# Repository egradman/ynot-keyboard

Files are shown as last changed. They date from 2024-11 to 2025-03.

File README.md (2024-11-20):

# zmq-corne6

This is the repo for my "ynot" keyboard.

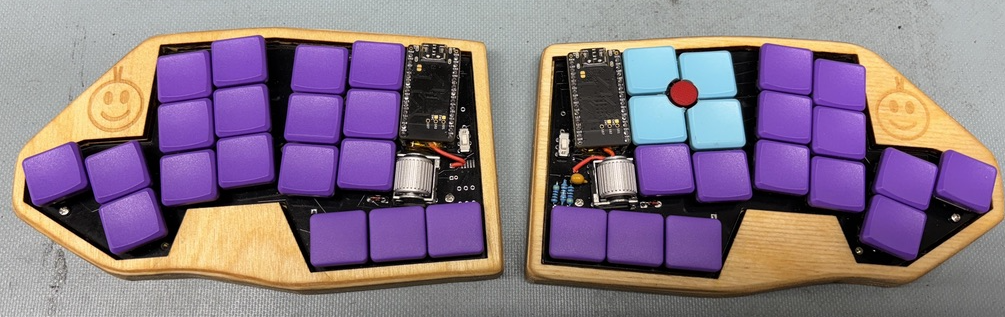
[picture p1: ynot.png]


it uses:

- Panasonic EVQWGD001 (purchased from keebd, but you can find them on aliexpress)
- nicenano
- a r61 trackpoint harvested from this keyboard https://www.ebay.com/itm/255174965511.  see https://deskthority.net/wiki/TrackPoint_Hardware for the pinout.
- choc kailh whites
- custom laser cut case
- battery:  3.7v 110mAh 301230 see (https://typeractive.xyz/products/lithium-battery-110mah)

trackpoint reset circuit as described here https://github.com/alonswartz/trackpoint

and the firmware provided by infusedkim https://github.com/infused-kim/kb_zmk_ps2_mouse_trackpoint_driver

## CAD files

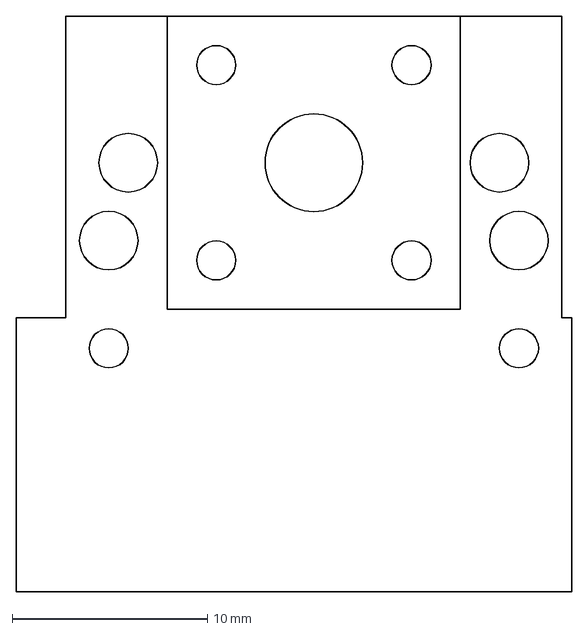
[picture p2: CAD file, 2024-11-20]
kicad_project/trackpoint.dxf
28.4 x 29.5 mm

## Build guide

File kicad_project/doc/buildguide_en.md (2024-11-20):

# Build Guide

This is the build guide for Cho-Corne-Ice, a Corne v3 variant designed for low profile and wireless
[Click here for the Corne Cherry v2 build guide](
https://github.com/foostan/crkbd/blob/master/corne-cherry/doc/v2/buildguide_en.md).

## Parts

| Name | Count | Remarks |
|:-|:-|:-|
| PCB | 1 set | |
| Top plate | 2 sheets | 1.2mm thick |
| Bottom plate | 2 sheets | |
| Display cover | 2 sheets | |
| nice!nano | 2 | |
| nice!view | 2 | |
| [Microcontroller Sockets](https://www.digikey.com/en/products/detail/mill-max-manufacturing-corp/310-43-112-41-001000/1212186) | 4 x 12pin | Mill-Max 310 series |
| [Microcontroller Pins](https://www.digikey.com/en/products/detail/mill-max-manufacturing-corp/3320-0-00-15-00-00-03-0/4147392) | 48 | Mill-Max 3320 series |
| Battery receptacle | 2 | JST-PH 2.0 SMD right angle S2B-PH-SM4-TB |
| Battery | 2 | Any 3.7v LiPo battery; 301230 fits between nice!nano and PCB |
| Reset switch | 2 | Alps SKSNLAE010 |
| Power switch | 2 | Alps SSSS811101 |
| Diodes | 42 | SMD Only (SOD-123 Package) |
| PCB sockets | 42 | Kailh Choc v1 (PG1350) |
| Key switches | 42 | Only compatible with Kailh Choc style |
| Keycaps | 42 pieces | 1u 40 pcs, 1.5u 2 pcs |
| Spacer M2 4.5mm | 10 | |
| Spacer M2 9mm | 4 | |
| Screw M2 4mm | 28 screws | |
| Rubber feet | 8 pieces | |
| USB-C cable | 2 | Avoid charge-only cables |

## Firmware preparation

It is recommended to flash nice!nano's prior to soldering.\
For more information,
please see <https://zmk.dev/docs>.

## Verification

The PCB comes with a frame for manufacturing reasons.
You can fold it by hand to remove it, but if it is difficult,
make a cut in the joint\* with a cutter or similar,
to make it easier to remove.
In addition, the joint can be cleaned with a file.

\**Joint part: There are a total of 8 parts,
which are marked in red in the image below.*

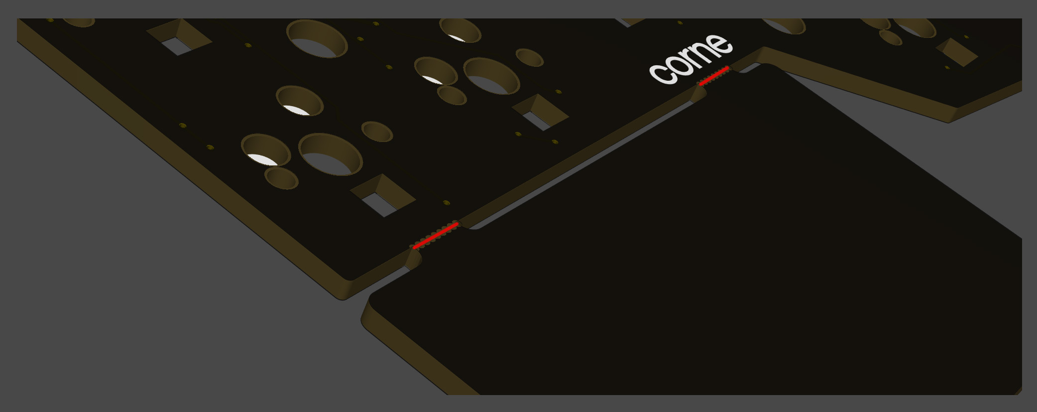
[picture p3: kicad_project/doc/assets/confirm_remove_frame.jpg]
confirm_remove_frame


## Assembly

### Diodes

Since SMD parts are very small, fine-tip/reverse-action tweezers are recommended.

**The diodes have a specific orientation**, so install with "|" marking on the diode
facing the "|" on the PCB marking: "|◁"

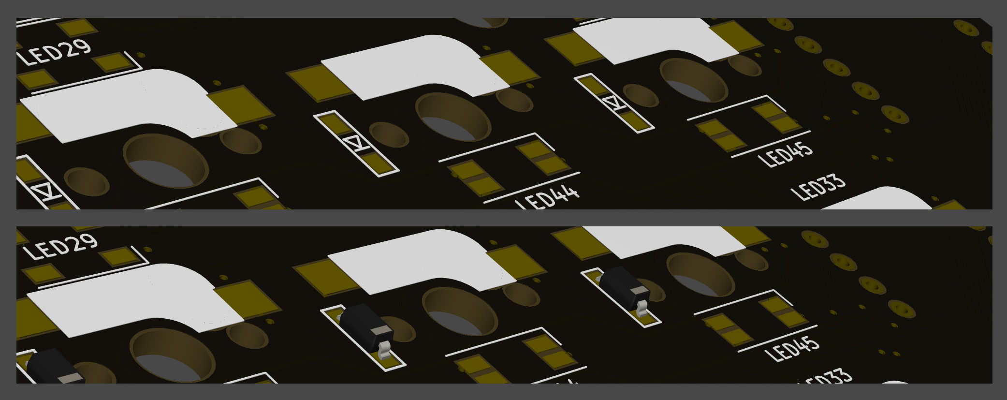
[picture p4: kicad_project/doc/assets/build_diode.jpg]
build_diode


<details>
<summary>TIPS: Tips for installing SMD parts</summary>

Begin with applying solder to only one pad.

tips_building_smd_01

Next, place SMD component while heating solder. At this time,
it is recommended to use [reverse-action tweezers](https://www.alimed.com/_resources/cache/images/product/70895A_850x480-pad.jpg),
so that you can hold the SMD part firmly without applying force,
and concentrate on alignment and soldering instead.
Also, if the soldering iron is too hot or the solder is touched too long,
the flux contained in the solder may evaporate and form a poor solder joint,
but it can be repaired later,
so at this point you should only care about attaching parts.
It's okay.

tips_building_smd_02

It is okay if the SMD component is not flush with the PCB when viewed from the side.
If it is floating, press the SMD component down with tweezers or your finger and reheat the solder.

tips_building_smd_03

Then solder the other contacts.
Be careful not to apply too much solder,
as a small amount is sufficient.
If you have applied too much,
you can remove it with a suction pump, solder wick,
or by picking it up with a soldering iron.

If the amount of solder on the preliminary solder side is small,
additional soldering is performed, and if it is a heap,
apply flux from above and heat it to clean it.

tips_building_smd_04

</details>

The diode is completed by soldering 42 pieces in total on the left and right.

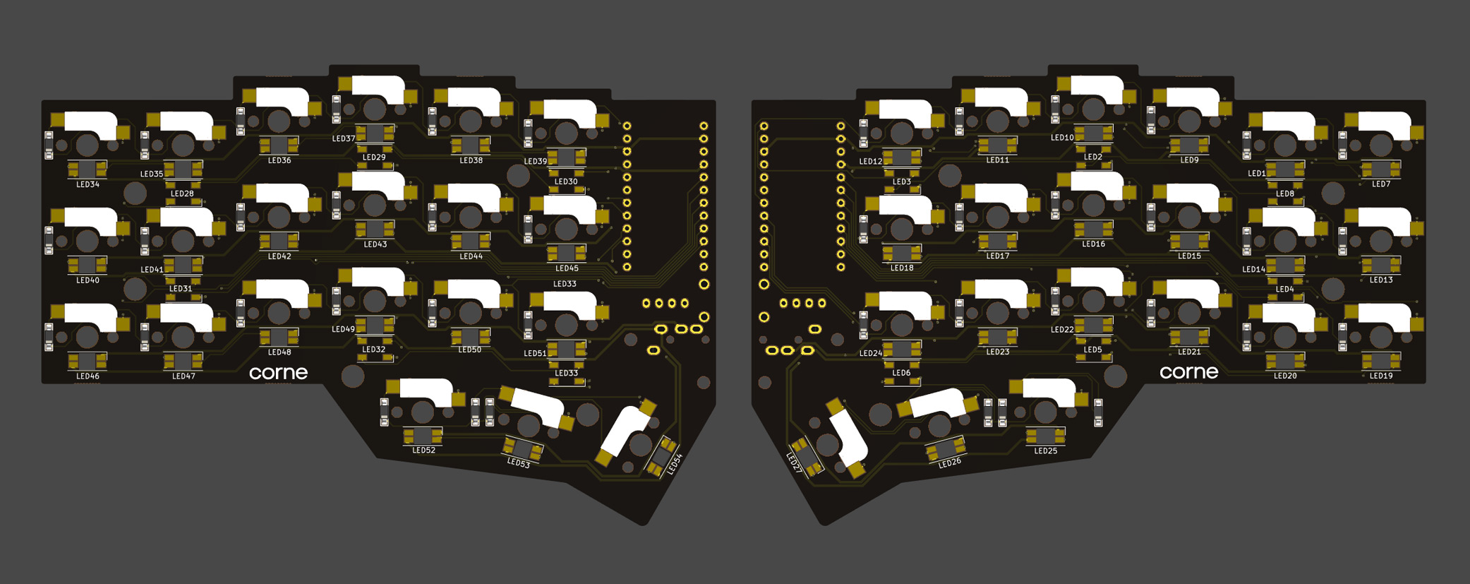
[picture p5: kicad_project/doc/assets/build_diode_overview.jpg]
build_diode_overview


### Power switch, reset switch, battery socket, pin socket for OLED

Solder the power switch, reset switch (tact switch),
and OLED pin socket.

The reset switch is a mid-mount switch and is mounted in the small cutout on the interior side of each half. the PCB will fit into the groove of the switch.

The power switch is SMD mounted to the bottom of the board directly under where the USB port will be located.

The JST-PH 2.0 2-pin battery receptacle is located near the reset switch and nice!nano header. The SMD version of this receptacle must be used, and it should be mounted facing toward the exterior of the board.

Since these parts may fall off when soldering, you can affix them with masking tape.

#### Battery

**Important**: There is no standard for battery polarity. Ensure your battery is terminated correctly before connecting to the board. Incorrect polarity will permanently damage your nice!nano.

### nice!nano

Solder headers to PCB. Then insert pins and solder nice!nano to pins. \[[Guide](https://www.digikey.com/en/products/detail/mill-max-manufacturing-corp/310-43-112-41-001000/1212186)]

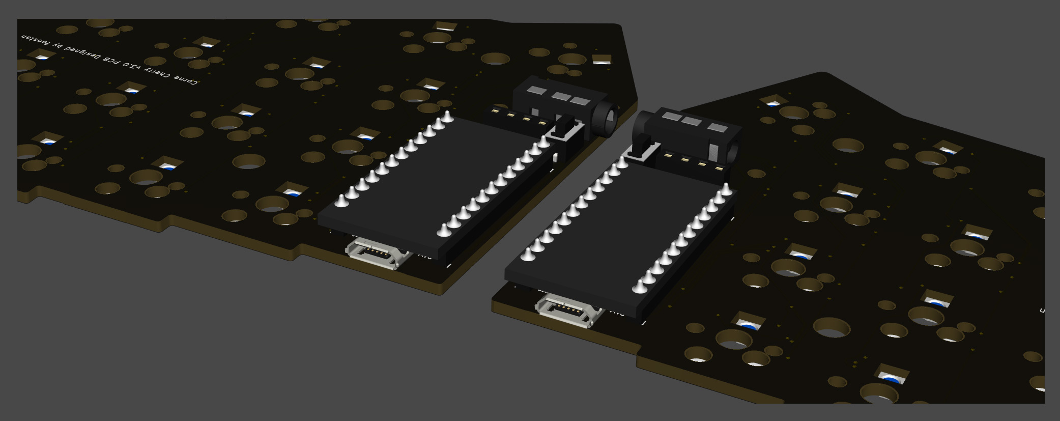
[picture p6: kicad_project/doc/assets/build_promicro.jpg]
build_promicro


If you use [spring-loaded pin headers](https://shop.yushakobo.jp/collections/all-keyboard-parts/products/31),
you do not need to solder the back side.
Please refer to the [Helix Build Guide](
https://github.com/MakotoKurauchi/helix/blob/master/Doc/buildguide_en.md#pro-micro)
for details on how to use spring-loaded pin headers.

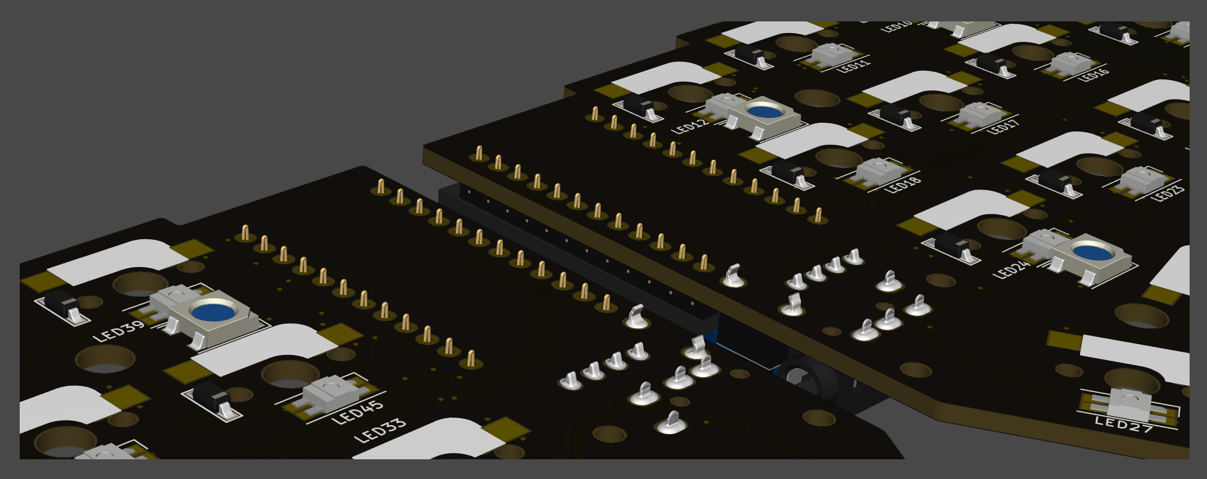
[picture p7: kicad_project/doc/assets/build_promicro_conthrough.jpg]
build_promicro_conthrough


### nice!view

Insert the pin header into the socket first, then solder the nice!view
to the pin header.
Note: Solder one pin to OLED module, then reheat solder to confirm nice!view module is level,
then solder remaining pins.

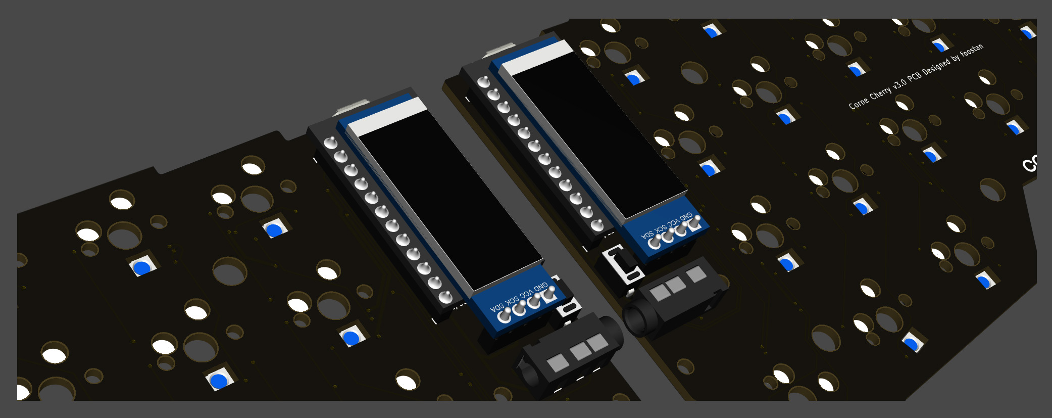
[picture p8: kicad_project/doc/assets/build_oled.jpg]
build_oled


### Operation check

Now is a good time to test your keyboard to help isolate potential problems.

To check the operation, connect left and right sides with TRRS cable,
then connect left side to the computer with USB cable.
If it is done correctly so far, shorting a hotswap socket pad with tweezers will 
output out a keypress and it will be displayed on the OLED module.

### Switch Sockets

Solder hotswap sockets according to mark on PCB as shown below.
Refer to **TIPS: Tips for installing SMD parts** section above as similar soldering
procedure is followed. 

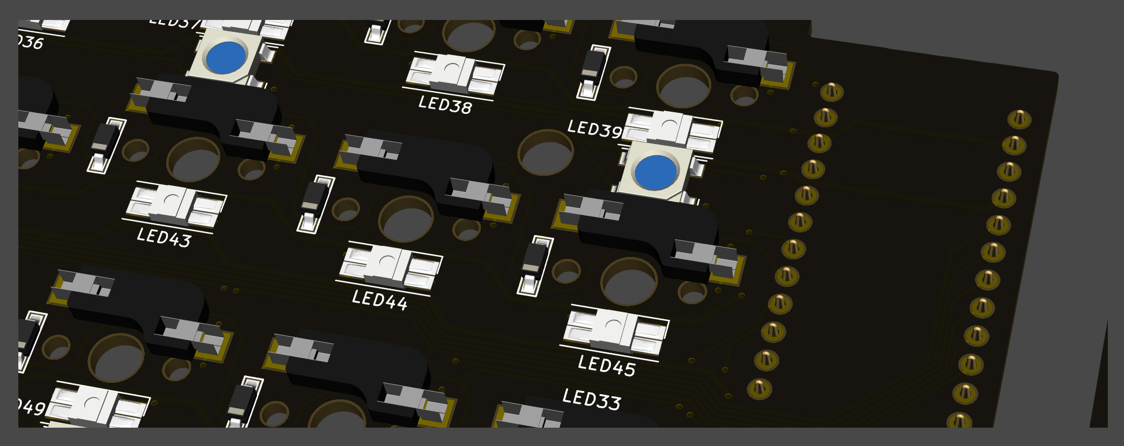
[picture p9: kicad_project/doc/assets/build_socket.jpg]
build_socket


Switch Socket soldering is completed after 42 are installed on left and right.

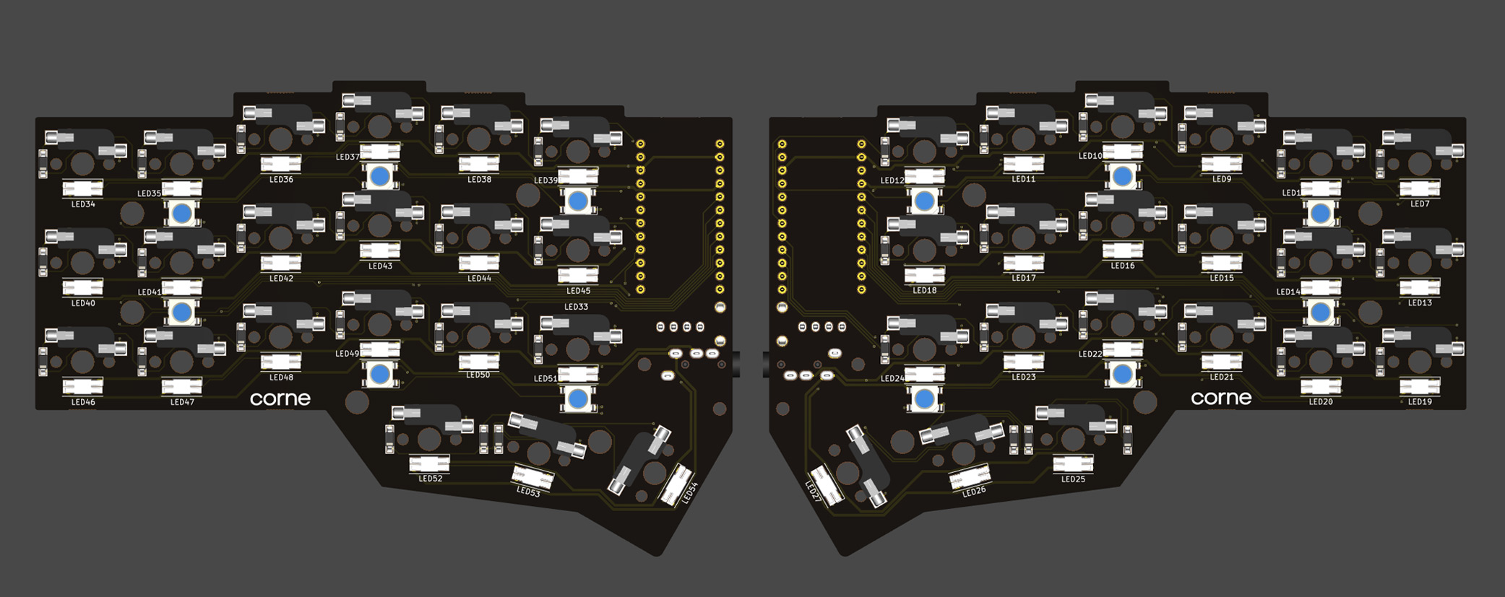
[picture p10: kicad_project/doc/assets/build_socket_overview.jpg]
build_socket_overview


### OLED protective cover

Attach the OLED protective cover with M2 9mm spacers and M2 screws.

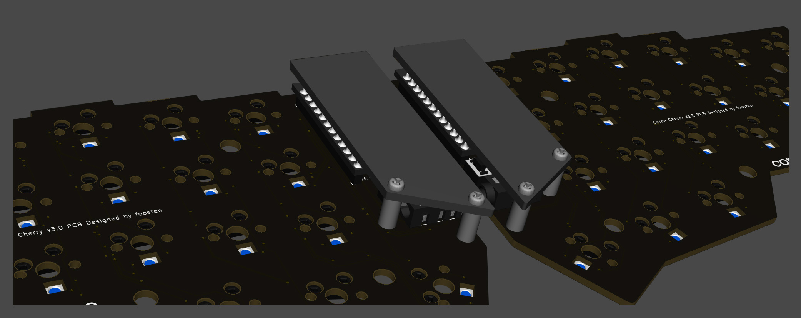
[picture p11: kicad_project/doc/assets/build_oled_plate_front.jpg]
build_oled_plate_front

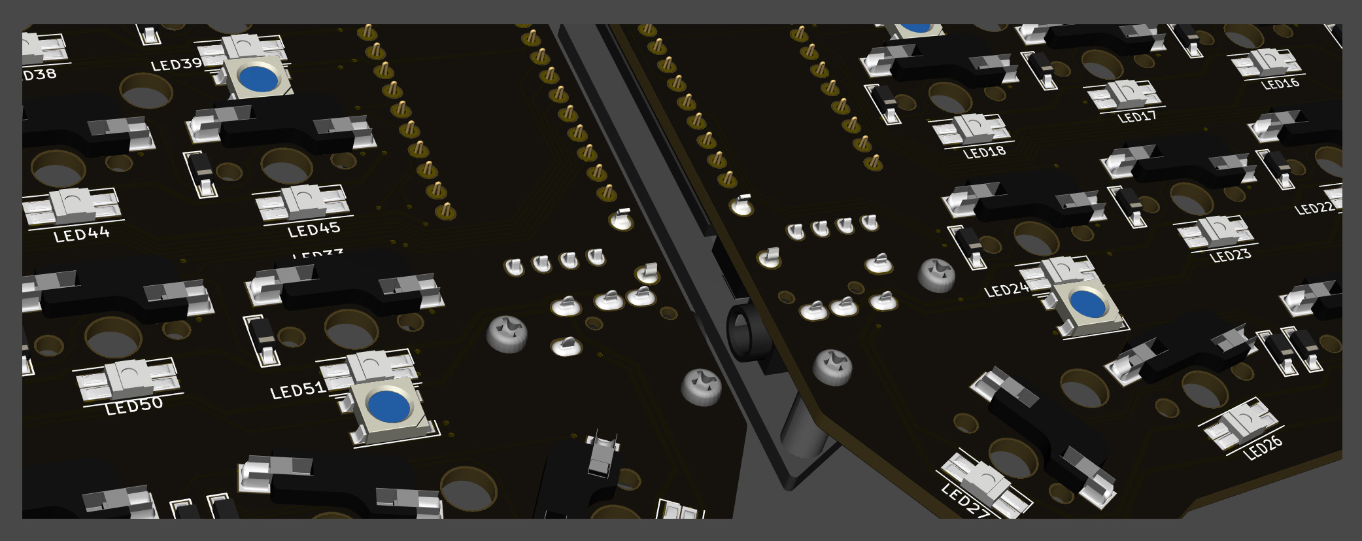
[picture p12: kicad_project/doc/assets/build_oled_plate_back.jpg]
build_oled_plate_back


### Plates & Switches

Place a few key switches into the top plate, then line up and press into PCB socket.
If you attach all the key switches to the top plate first,
it will be more difficult to fit them in the PCB sockets all at once.
So it is recommended to do a few to begin with. 

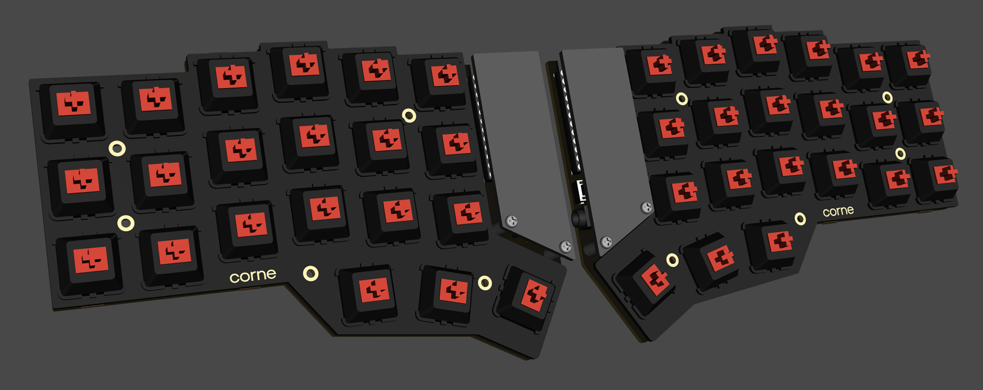
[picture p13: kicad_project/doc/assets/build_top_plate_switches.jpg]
build_top_plate_switches


Install the M2 4.5mm spacer and M2 screws on the top plate.

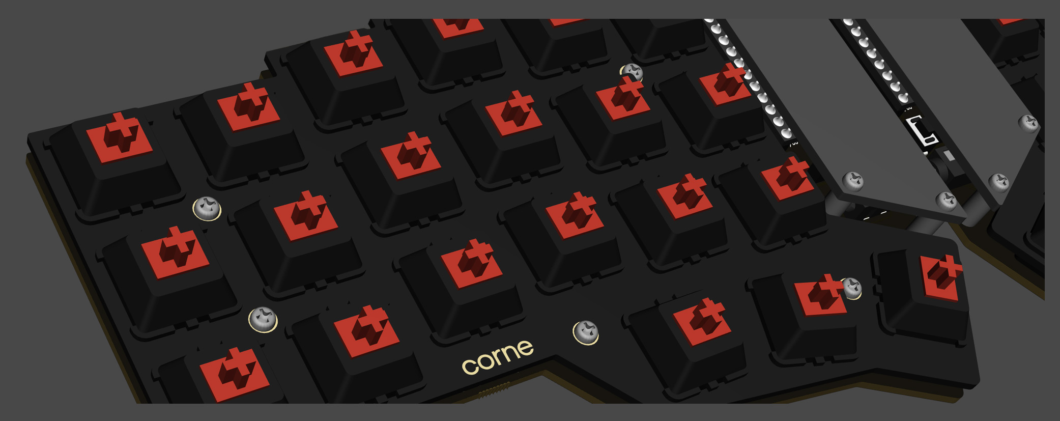
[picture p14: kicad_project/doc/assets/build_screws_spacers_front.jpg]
build_screws_spacers_front


It is easy to screw the spacer in after inserting it into the hole from the back side.

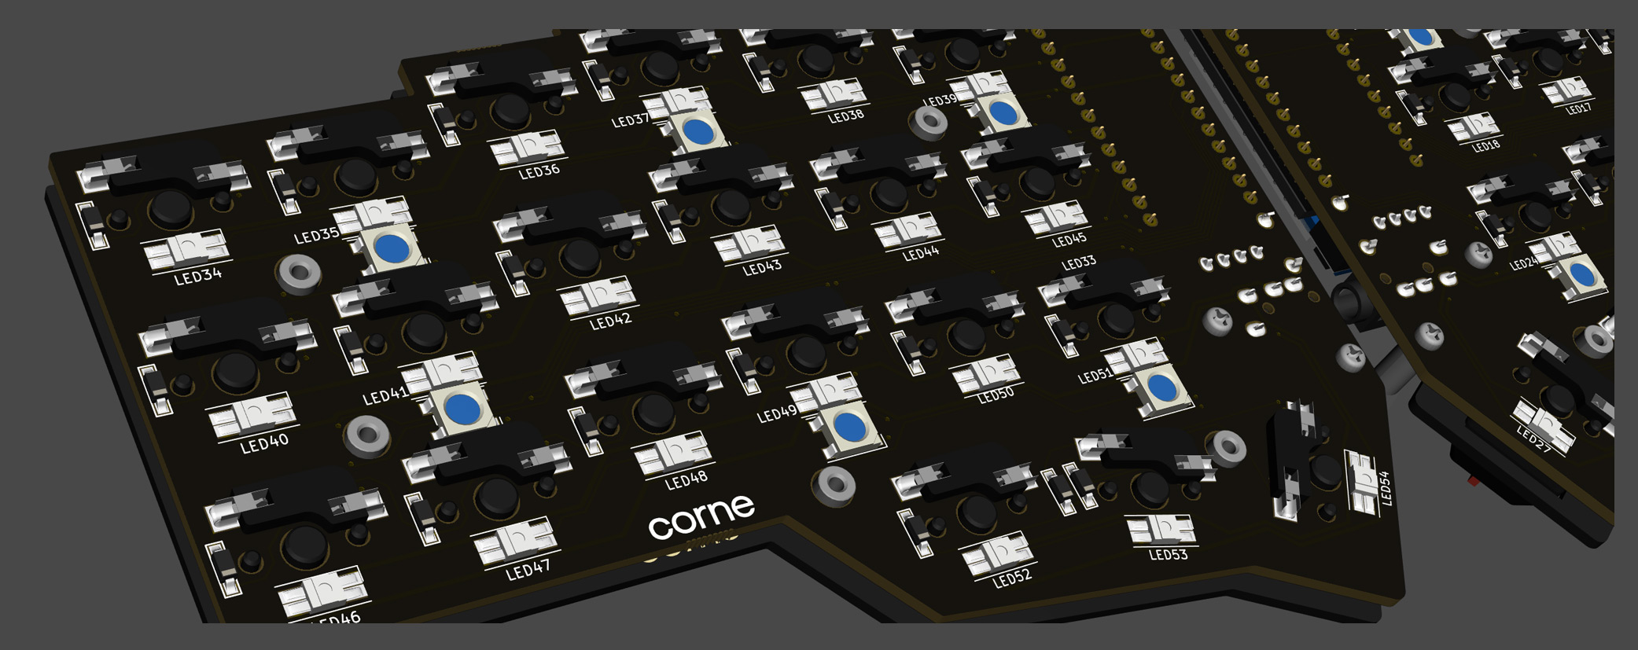
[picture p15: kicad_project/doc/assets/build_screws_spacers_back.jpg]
build_screws_spacers_back


Attach the bottom plate with M2 screws.

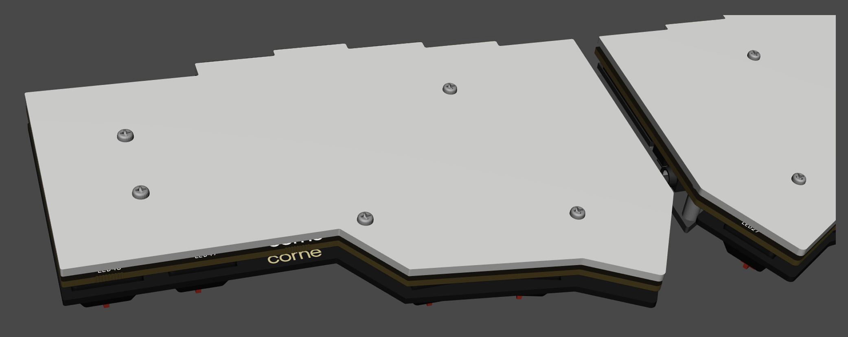
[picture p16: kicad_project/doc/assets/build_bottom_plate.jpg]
build_bottom_plate


Install the rubber feet in the following positions.

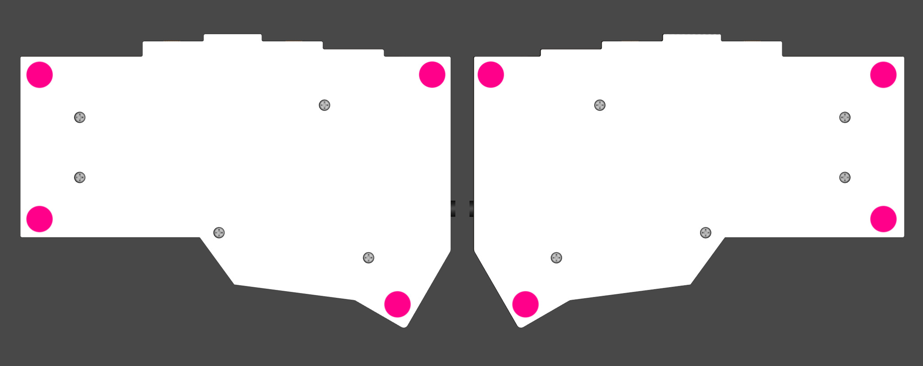
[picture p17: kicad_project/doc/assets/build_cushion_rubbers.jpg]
build_cushion_rubbers


That's it!

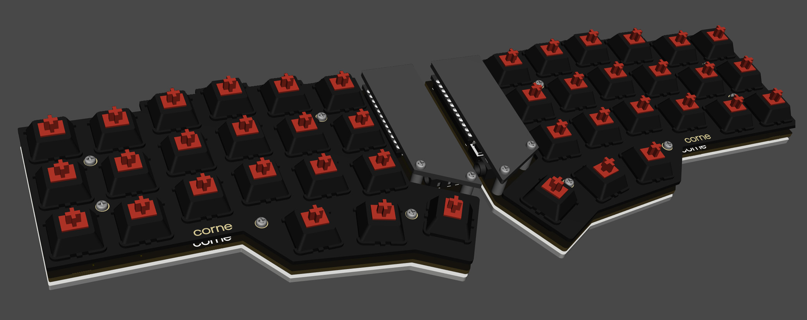
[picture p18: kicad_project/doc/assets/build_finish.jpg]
build_finish


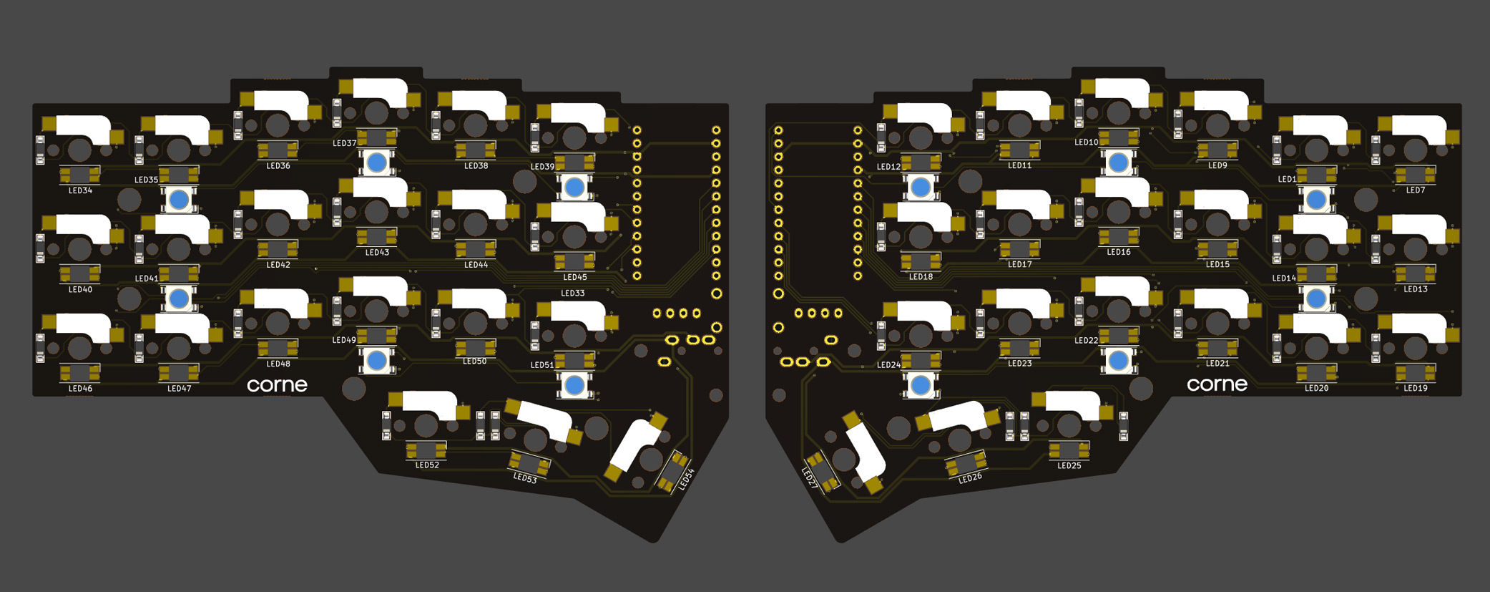
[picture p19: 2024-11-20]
kicad_project/doc/assets/build_led_undergrow_overview.jpg

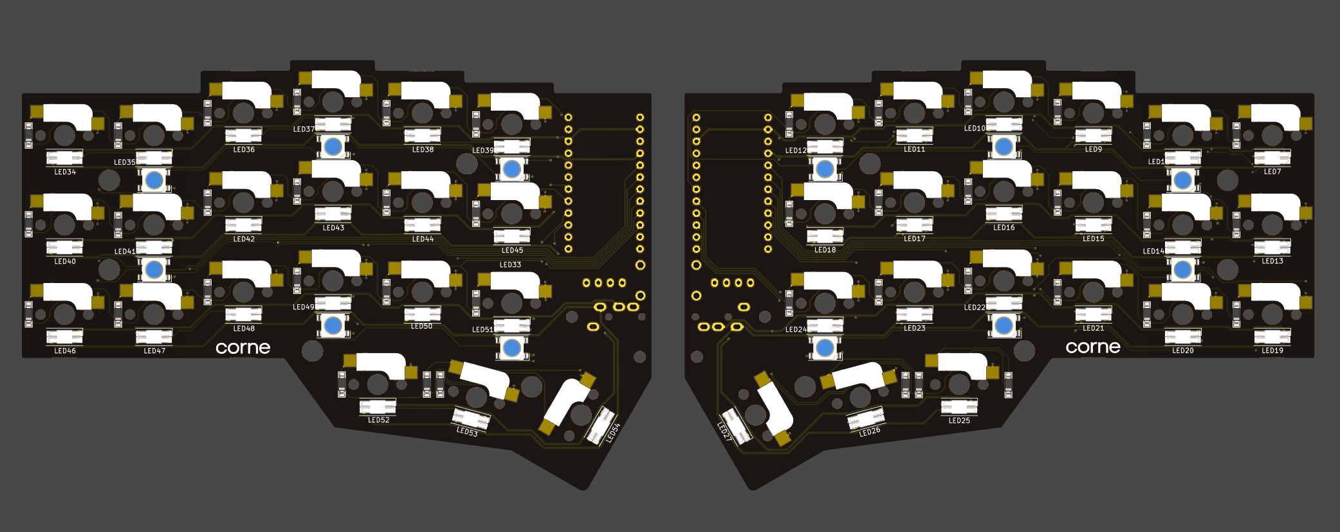
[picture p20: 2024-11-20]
kicad_project/doc/assets/build_led_back_overview.jpg

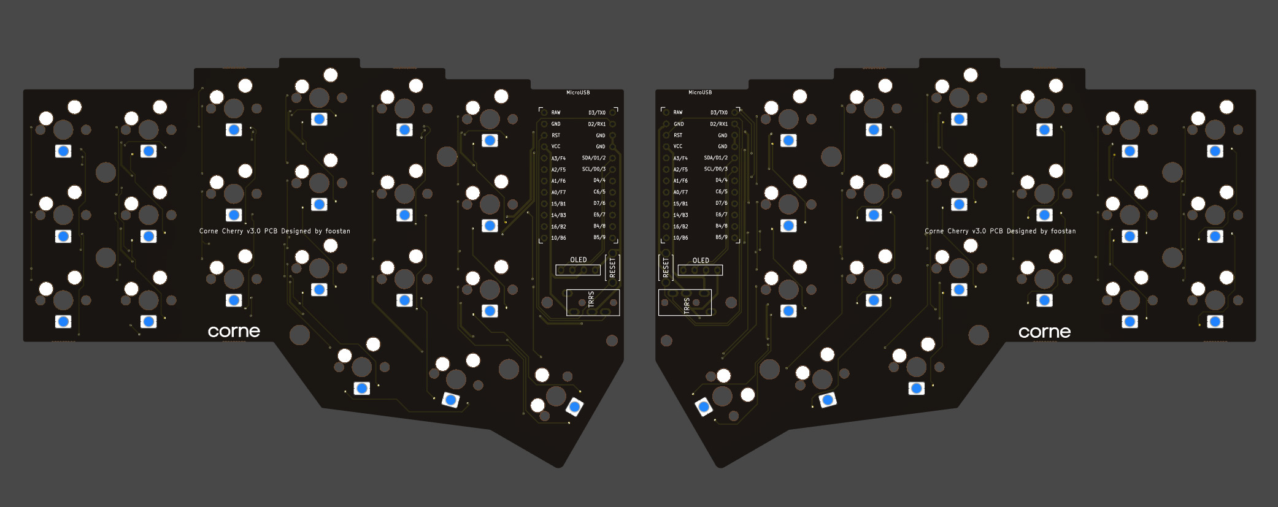
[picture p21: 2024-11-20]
kicad_project/doc/assets/build_led_front_overview.jpg

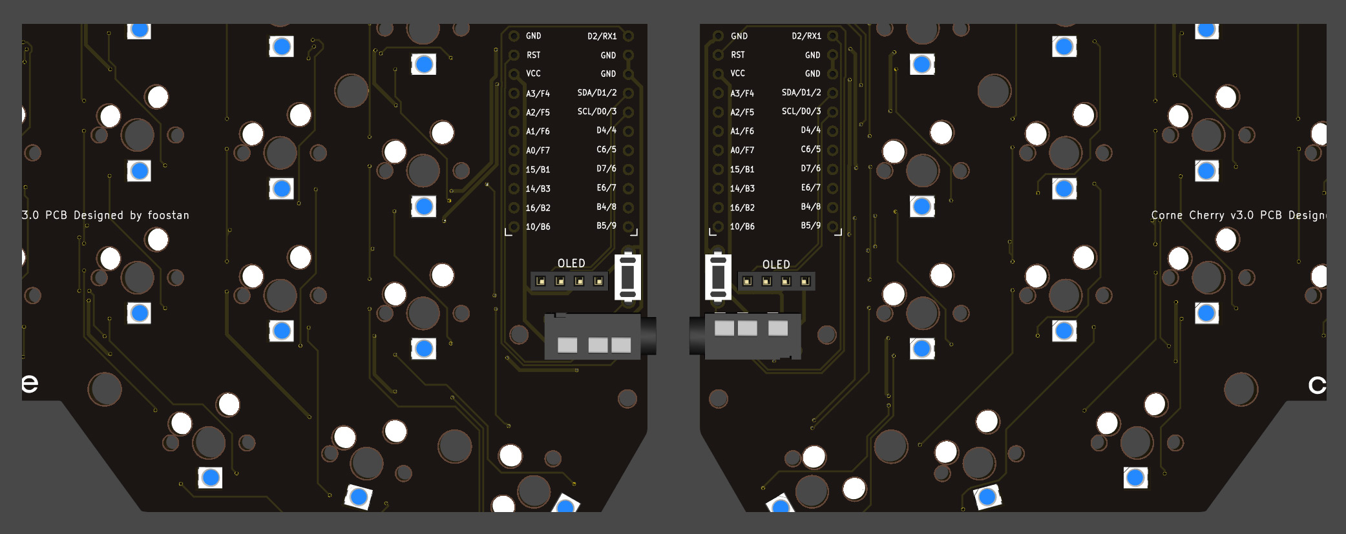
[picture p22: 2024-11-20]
kicad_project/doc/assets/build_trrs_reset_oled.jpg

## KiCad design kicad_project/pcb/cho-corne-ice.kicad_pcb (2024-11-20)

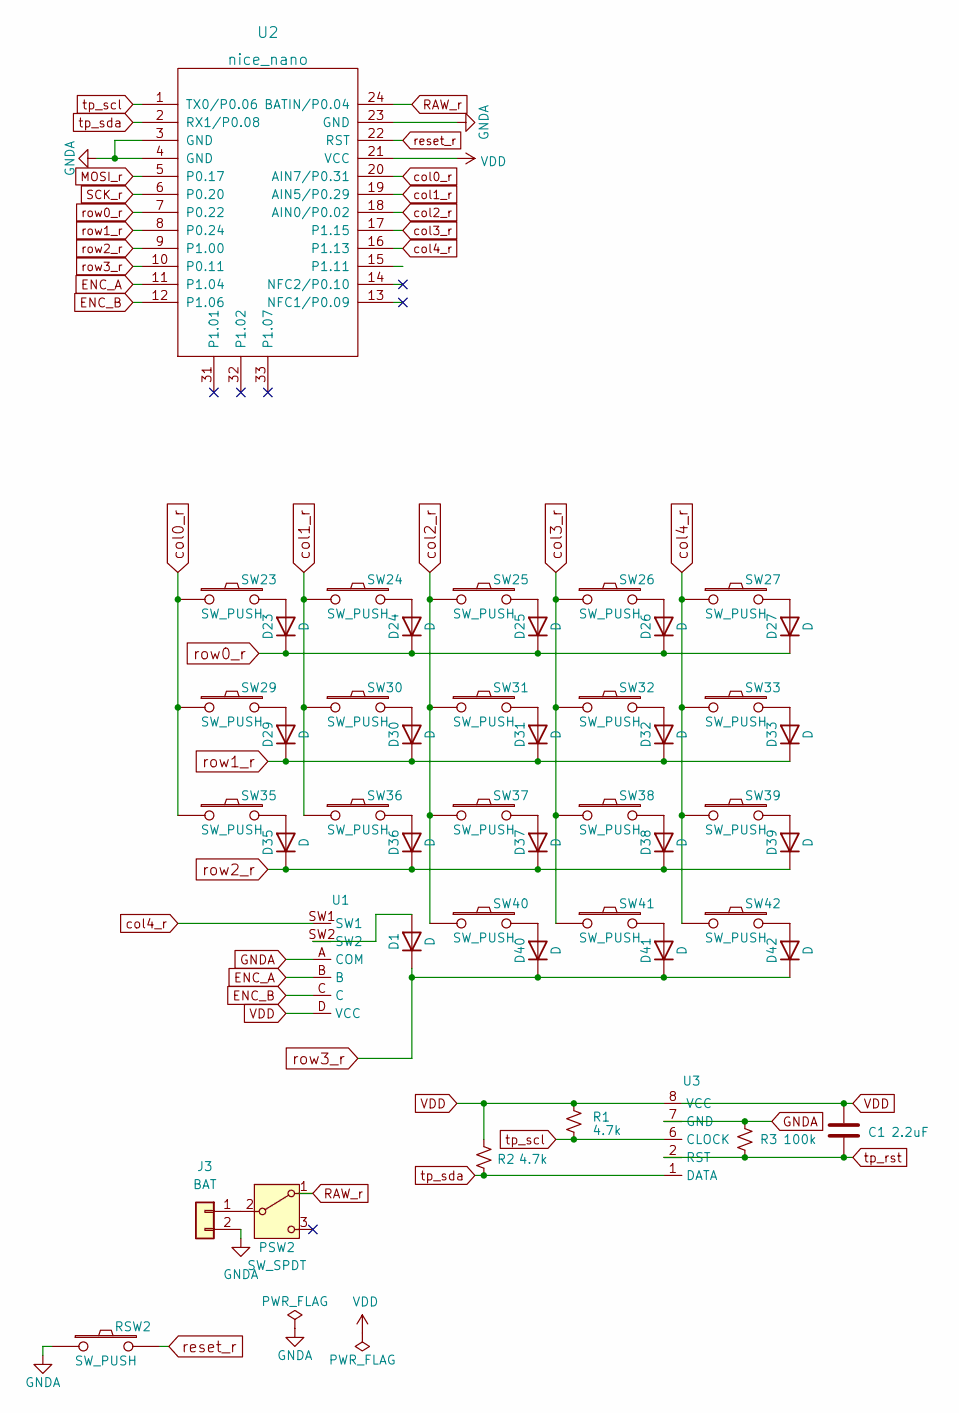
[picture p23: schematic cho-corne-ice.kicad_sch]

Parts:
C1: 2.2uF; CP_Radial_D4.0mm_P1.50mm
D1, D23, D24, D25, D26, D27, D29, D30, D31, D32, D33, D35, D36, D37, D38, D39, D40, D41, D42: D; ComboDiode
J3: BAT; SolderWire-0.1sqmm_1x02_P3.6mm_D0.4mm_OD1mm
PSW2: SW_SPDT; power_switch
R1, R2: 4.7k; R_Axial_DIN0204_L3.6mm_D1.6mm_P5.08mm_Horizontal
R3: 100k; R_Axial_DIN0204_L3.6mm_D1.6mm_P5.08mm_Horizontal
RSW2: SW_PUSH; reset_switch
SW23, SW24, SW25, SW26, SW27, SW29, SW30, SW31, SW32, SW33, SW35, SW36, SW37, SW38, SW39, SW40, SW41, SW42: SW_PUSH; SW_PG1350_reversible
U1: RollerEncoder_Panasonic_EVQWGD001
U2: nice_nano; ProMicro_jumpable_eric
U3: trackpoint

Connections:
ENC_A: U1.B, U2.11 (P1.04)
ENC_B: U1.C, U2.12 (P1.06)
GNDA: J3.2, R3.1, RSW2.1, U1.A (COM), U2.3 (GND), U2.4 (GND), U2.23 (GND), U3.7 (GND)
MOSI_r: U2.5 (P0.17)
unnamed: D1.2 (A), U1.SW2
unnamed: D23.2 (A), SW23.2
unnamed: D24.2 (A), SW24.2
unnamed: D25.2 (A), SW25.2
unnamed: D26.2 (A), SW26.2
unnamed: D27.2 (A), SW27.2
unnamed: D29.2 (A), SW29.2
unnamed: D30.2 (A), SW30.2
unnamed: D31.2 (A), SW31.2
unnamed: D32.2 (A), SW32.2
unnamed: D33.2 (A), SW33.2
unnamed: D35.2 (A), SW35.2
unnamed: D36.2 (A), SW36.2
unnamed: D37.2 (A), SW37.2
unnamed: D38.2 (A), SW38.2
unnamed: D39.2 (A), SW39.2
unnamed: D40.2 (A), SW40.2
unnamed: D41.2 (A), SW41.2
unnamed: D42.2 (A), SW42.2
unnamed: J3.1, PSW2.2 (B)
RAW_r: PSW2.1 (A), U2.24 (BATIN/P0.04)
SCK_r: U2.6 (P0.20)
VDD: C1.1, R1.1, R2.1, U1.D (VCC), U2.21 (VCC), U3.8 (VCC)
col0_r: SW23.1, SW29.1, SW35.1, U2.20 (AIN7/P0.31)
col2_r: SW25.1, SW31.1, SW37.1, SW40.1, U2.18 (AIN0/P0.02)
col3_r: SW26.1, SW32.1, SW38.1, SW41.1, U2.17 (P1.15)
reset_r: RSW2.2, U2.22 (RST)
row0_r: D23.1 (K), D24.1 (K), D25.1 (K), D26.1 (K), D27.1 (K), U2.7 (P0.22)
row1_r: D29.1 (K), D30.1 (K), D31.1 (K), D32.1 (K), D33.1 (K), U2.8 (P0.24)
row2_r: D35.1 (K), D36.1 (K), D37.1 (K), D38.1 (K), D39.1 (K), U2.9 (P1.00)
row3_r: D1.1 (K), D40.1 (K), D41.1 (K), D42.1 (K), U2.10 (P0.11)
tp_rst: C1.2, R3.2, U3.2 (RST)
tp_scl: R1.2, U2.1 (TX0/P0.06), U3.6 (CLOCK)
tp_sda: R2.2, U2.2 (RX1/P0.08), U3.1 (DATA)

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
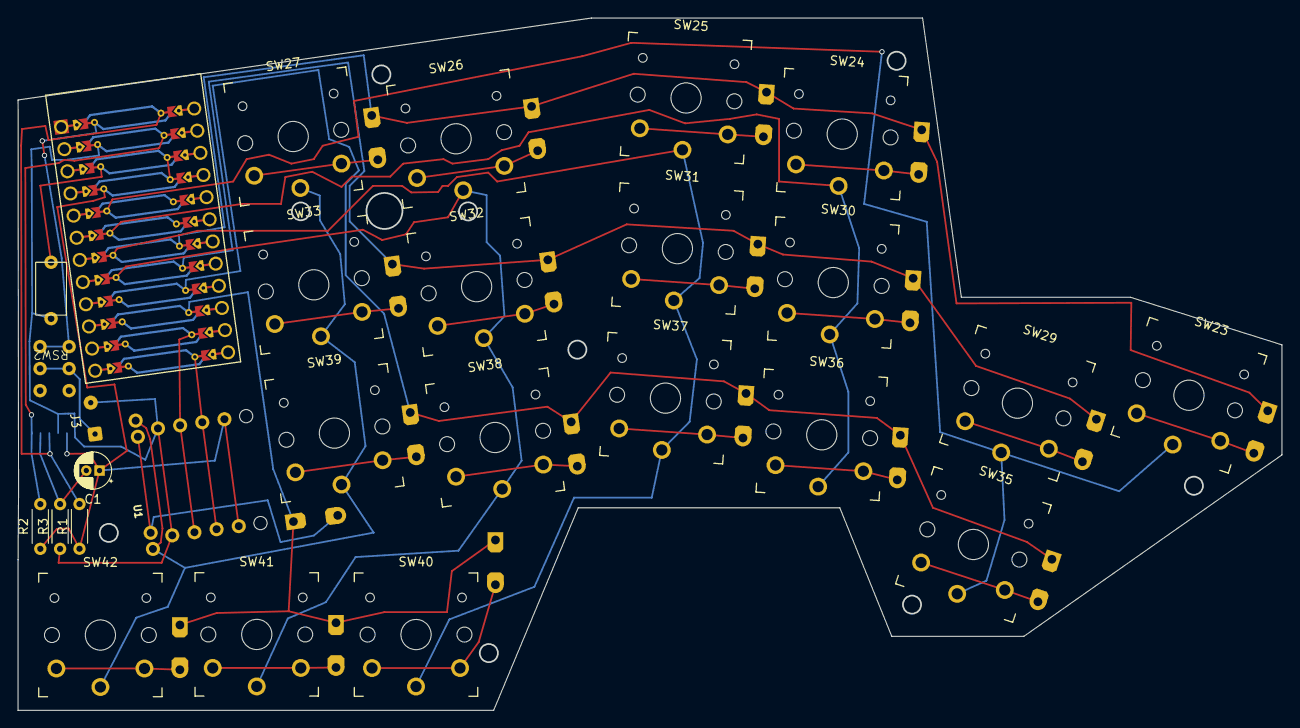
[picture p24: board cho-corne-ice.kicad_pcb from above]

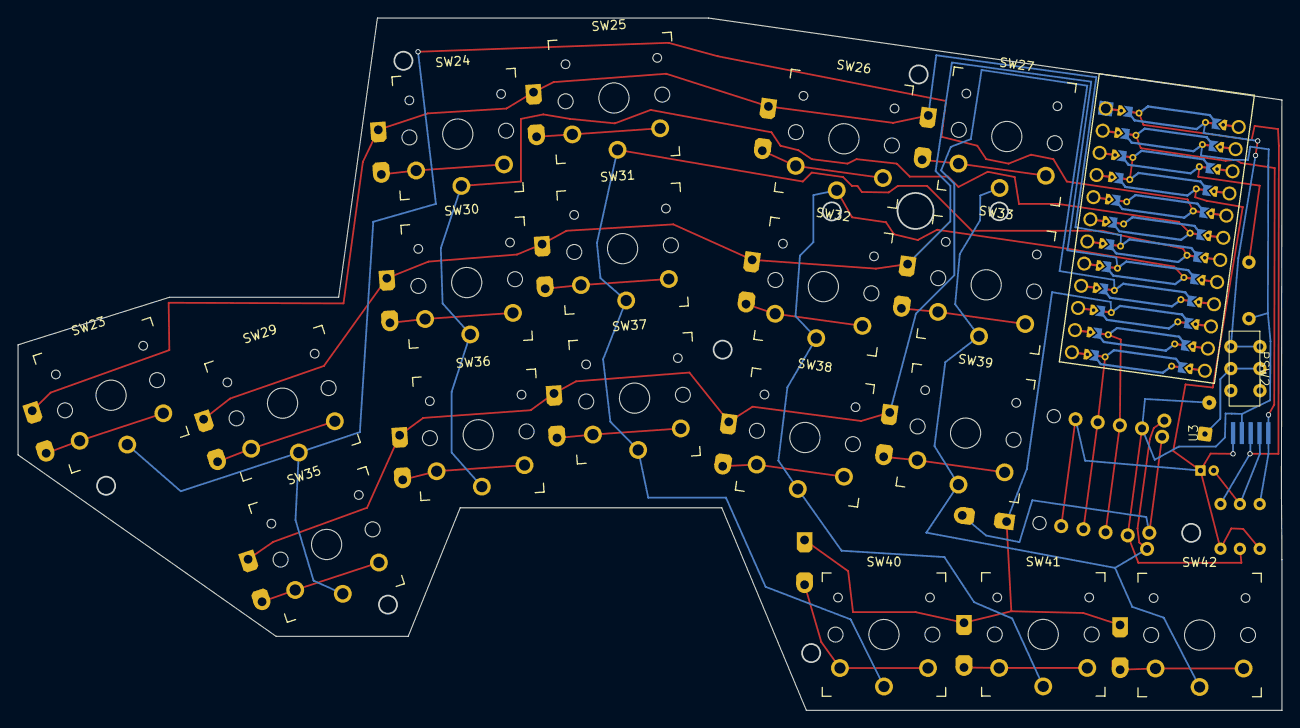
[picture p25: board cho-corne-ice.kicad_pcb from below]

Board: 2 copper layers, 143.5 x 78.6 mm, 47 parts (20 on the bottom side), 38 nets.

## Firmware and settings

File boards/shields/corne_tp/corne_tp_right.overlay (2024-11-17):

/*
 * Copyright (c) 2020 Pete Johanson
 *
 * SPDX-License-Identifier: MIT
 */

#include "corne_tp.dtsi"

&five_column_transform {
    col-offset = <5>;
};

&kscan0 {
    col-gpios
        = <&pro_micro 15 GPIO_ACTIVE_HIGH>
        , <&pro_micro 18 GPIO_ACTIVE_HIGH>
        , <&pro_micro 19 GPIO_ACTIVE_HIGH>
        , <&pro_micro 20 GPIO_ACTIVE_HIGH>
        , <&pro_micro 21 GPIO_ACTIVE_HIGH>
        ;
};

&encoder_right {
    status = "okay";
};


/*
 * PS/2 Mouse / Trackpoint - User Configuration
 *
 * Enable PS/2 drivers on this side of the keyboard.
 * It MUST be the central half. If you connected your TP or mouse to the
 * left side, then move the following content to `your_keyboard_left.overlay`
 *
 * You also need to adjust `Kconfig.defconfig` and configure that this side
 * is the central side.
 *
 */


// Pick the PS/2 driver
//
// Comment out the following define to use the PS/2 GPIO driver instead of the
// UART driver.
//
// Both, the UART and GPIO drivers, implement the PS/2 protocol and work with
// trackpoints and other mouse devices that use PS/2.
//
// The only difference is which hardware they use on your controller to
// transmit the data. The UART driver has MUCH better performance and should
// be used by most people.
//
// The GPIO driver should only be used if your PS/2 pointing device uses a
// clock frequency rate that is not compatible with the UART baud rates. Or
// if you are NOT using a nrf52-based controller, such as the nice!nano,
// nice!nano clone or a seeduino xiao.
//
// In all other cases you should try using the UART driver first.
#define MOUSE_PS2_DRIVER_UART


// Configure the SCL and SDA pins using the`&pro_micro` notation.
//
// If possible, try to choose the blue high frequency pins to avoid
// bluetooth interference.
//
// It will still work even if you pick low frequency pins, but there is a risk
// that the trackpoint could cause bluetooth interference.
//
// On the nice!nano documentation these are green DX pins:
// https://nicekeyboards.com/docs/nice-nano/pinout-schematic
//
// The ideal pins are...
//   - D1 and D0 for clock and data, because they are high frequency.
//   - D8, D9, D16 or D10 for the trackpoint reset pin, because it doesn't
//     need to be high frequency (only needed if you are not using a reset
//     circuit)
//
// But on the corne keyboard, these pins are used for the backlight. So, this
// example config uses the pins D16 and D10 for clock and data and
// D9 for the reset circuit.
#define MOUSE_PS2_PIN_SCL_PRO_MICRO <&pro_micro 1 GPIO_ACTIVE_HIGH>
#define MOUSE_PS2_PIN_SDA_PRO_MICRO <&pro_micro 0 GPIO_ACTIVE_HIGH>

// Configure the Power-On-Reset pin
//
// Uncomment and configure this pin if you have an extra free pin and want the
// controller to perform the Power-On-Reset sequence, which many trackpoints
// require.
//
// You don't need this if you are not using a trackpoint or if you have a
// trackpoint reset circuit.
//
// It's ok to use a low-frequency pin for this.
// #define MOUSE_PS2_PIN_RST_PRO_MICRO <&pro_micro 9 GPIO_ACTIVE_HIGH>


// Configure SDA pin using the pinctrl notation
//
// Now configure SDA pin using the pinctrl notation. Make sure to use the same
// pin as in the pro micro notation, but convert it to the pinctrl notation.
//
// For the nice!nano you can find it on their pinout schematic, next to the
// pins, in the blue or violet boxes, with a format like `PX.YY` (P0.09).
//
// Enter it like `X, Y` without leading zeroes.
//
// Examples:
//      D1  - P0.06: 0, 6
// 		D0  - P0.08: 0, 8
//		D15 - P1.13: 1, 13
//		D16 - P0.10: 0, 10
//		D10 - P0.09: 0, 9
//
// We don't define the SCL pin, because UART uses a baud rate instead of
// a clock pin.
#define MOUSE_PS2_PIN_SDA_PINCTRL <NRF_PSEL(UART_RX, 0, 8)>
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

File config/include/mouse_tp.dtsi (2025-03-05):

#ifdef HAS_MOUSE_TP
  #include <dt-bindings/zmk/mouse.h>
  #include <dt-bindings/zmk/mouse_settings.h>
  #include <behaviors/mouse_keys.dtsi>
  #include <behaviors/mouse_setting.dtsi>

 /*
  * Key Behaviors to adjust settings
  */

  // They key codes below can be used to adjust the TP settings at runtime
  // without needing to recompile the firmware.
  //
  // The values will be logged and saved in the config on the controller flash
  // after 60s (CONFIG_ZMK_SETTINGS_SAVE_DEBOUNCE).
  //
  // On boot the settings will be restored again.
  //
  // If you prefer a more explicit way of configuration, you can also hardcode
  // these settings in `&mouse_ps2`.
  //
  // If you set these settings in `&mouse_ps2`, you will still be able to
  // adjust the values during runtime with these key codes, but after
  // restarting the board the values in `&mouse_ps2` will be restored and not
  // the ones stored in the flash using the key codes.


  // How sensitive the trackpoint is
  #define U_MSS_TP_S_I &mms MS_TP_SENSITIVITY_INCR
  #define U_MSS_TP_S_D &mms MS_TP_SENSITIVITY_DECR


  // The maximum speed the trackpoint will accelerate to
  #define U_MSS_TP_V6_I &mms MS_TP_VALUE6_INCR
  #define U_MSS_TP_V6_D &mms MS_TP_VALUE6_DECR


  // I am not quite sure tbh... default seems fine.
  #define U_MSS_TP_NI_I &mms MS_TP_NEG_INERTIA_INCR
  #define U_MSS_TP_NI_D &mms MS_TP_NEG_INERTIA_DECR


  // How hard you have to press to activate the "Press To Select" feature that
  // lets you tap or press on the trackpoint to click.
  //
  // Not all trackpoints support it and you have to enable
  // `tp-press-to-select;` in `&mouse_ps2` first.
  #define U_MSS_TP_PT_I &mms MS_TP_PTS_THRESHOLD_INCR
  #define U_MSS_TP_PT_D &mms MS_TP_PTS_THRESHOLD_DECR


  // If you mess up the settings, you can use this key code to clear the
  // settings from flash and re-set the default values on the TP.
  //
  // Make sure to wait at least CONFIG_ZMK_SETTINGS_SAVE_DEBOUNCE seconds (60
  // by default) before restarting the board to ensure the settings are
  // written to flash storage.
  #define U_MSS_RESET   &mms MS_RESET


  // If you prefer to set the settings in `&mouse_ps2`, you can use the key
  // codes above to find the settings you like the most and then press this
  // key code to output the settings to the log.
  //
  // Then you can add those values to `&mouse_ps2`
  #define U_MSS_LOG     &mms MS_LOG


  // Only apply these settings on the side that has the TP connected
  // (usually the right side)
  #ifdef MOUSE_PS2_DT_PRESENT

   /*
    * Input Listener Config
    */

    &mouse_ps2_input_listener {

      // Adjust pointing device axes.
      // This adjusts the values inside the zmk driver. Some
      // trackpoints also allow you to adjust it in their firmware. Check
      // the driver options below for more info.
      // xy-swap;
      // x-invert;
      y-invert;

      // Set the layer that should automatically activate when the mouse is
      // moving.
      layer-toggle = <MOUSE_TP>;

      // How long the mouse needs to move for before the layer is activated (to
      // avoid accidental activations while typing) (Default: 250)
      layer-toggle-delay-ms = <250>;

      // How long to wait, after the last mouse movement, before deactivating
      // the layer (Default: 250)
      layer-toggle-timeout-ms = <500>;
    };


   /*
    * Mouse Driver Settings
    */

    &mouse_ps2 {

      // How sensitive the TP is (Default: 128)
      tp-sensitivity = <100>;


      // The maximum mouse movement speed the TP will accelarate to
      // (Default: 97)
      tp-val6-upper-speed = <120>;


      // Negative Inertia (Default: 6)
      // Makes the TP feel more responsive and "overshoot" less.
      // tp-neg-inertia = <6>;


      // Enable clicking by tapping on the TP.
      // Not all TPs support this.
      // tp-press-to-select;
      // tp-press-to-select-threshold = <10>;


      // Adjust axis settings on the TP
      // Works only on some trackpoints, but may be properly considered by the
      // trackpoint's acceleration features (which may or may not have an
      // impact).
      //
      // Alternatively consider achieving the same effect using the
      //  `input-listener` settings below.
      // tp-xy-swap;
      // tp-x-invert;
      // tp-y-invert;


      // Set sampling rate
      //
      // The frequency at which the mouse samples and sends data (in hz).
      // The default rate is 100. You can try lowering it if you experience
      // connection errors.
      //
      // Higher values than 100 are no improvement in my experience, but will
      // increase battery life and potentially errors in transmissions.
      //
      // These values are allowed: 10,20,40,60,80,100,200
      // sampling-rate = <60>;


      // Disables clicking.
      // Useful when using the PS2 GPIO driver that is prone to
      // erros in transmissions to reduce accidental clicks.
      // disable-clicking;
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

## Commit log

2024-10-14 les logging
2024-10-14 uart logging
2024-10-14 scroll and buttons
2024-11-17 attempt at encoder bindings
    [corne_tp_right.overlay]
2024-11-20 added kicad
    [cho-corne-ice-B_Cu.gbl, cho-corne-ice-B_Mask.gbs, cho-corne-ice-B_Paste.gbp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]
